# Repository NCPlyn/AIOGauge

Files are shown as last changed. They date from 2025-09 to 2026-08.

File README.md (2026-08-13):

# AIOGauge

All-In-One-Oil-Gauge; a ESP32S3 project that uses:
- **PST-F 1** Bosch pressure and temperature [sensor](https://www.bosch-motorsport.com/content/downloads/Raceparts/en-GB/54249355.html) (0261230482 / 0261230341 / 0261230340 etc + 1928405159 connector)
- **LSM6DS3** accelerometer for G force realtime monitor
- **ATGM336H** GPS for realtime speed monitor + 0-100km/h / 0-60mph 10Hz timer
- **GC9A01** round TFT display shows all information
- **Logs** last 10 hours of measurements to view later at 2Hz
- **WiFi** to update the firmware, change settings, view logged graphs of values and have **live view** alongs side the display!
- Two buttons to edit setting on the device itself
- **STLs** for 3D printed enclosure in /enclosure, screwed together with M3x16

**Project in development**

## Photos

<div style="display:flex">
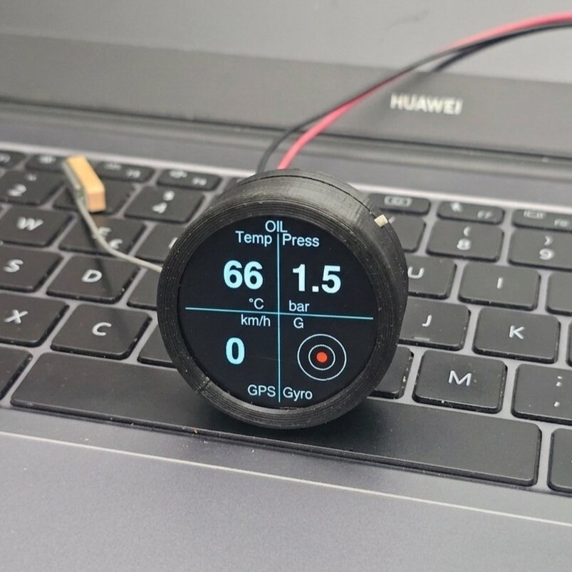
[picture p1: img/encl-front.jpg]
front

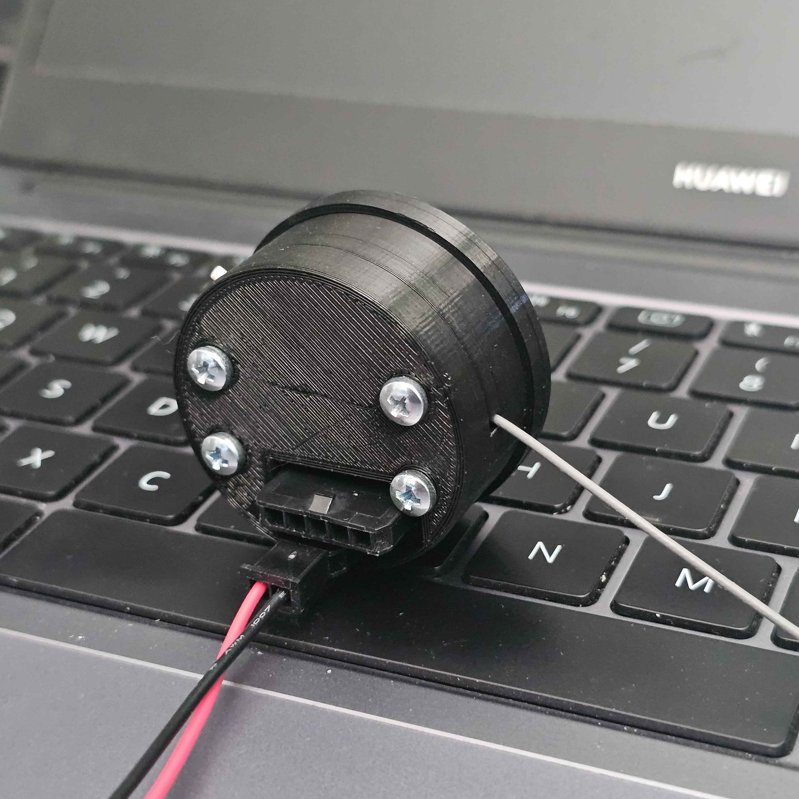
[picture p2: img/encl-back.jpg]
back

</div>
*Finished gauge in 3D printed enclosure*

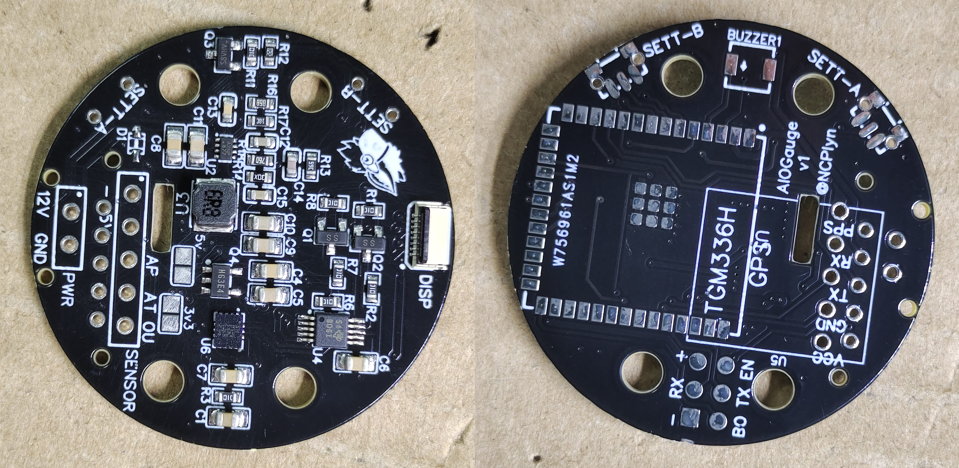
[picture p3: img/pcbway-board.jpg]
Prototype PCB
  
*PCBWay provided & preassembled PCB*  

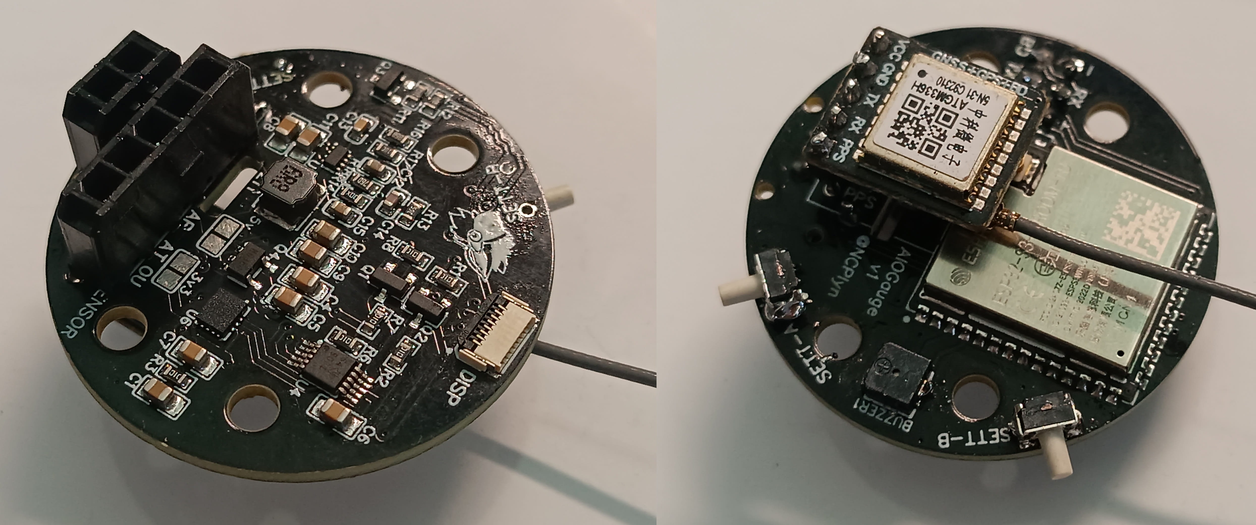
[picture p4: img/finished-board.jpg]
Assembled PCB
  
*Soldered rest of the components*  

## Sponsored by PCBWay

This project was made possible thanks to **[PCBWay](https://www.pcbway.com/)**, who kindly sponsored the **prototype PCBs** and handled the **SMD assembly**.

The PCBWay team discussed with me which parts would be sourced and used, and they were even able to assemble just a **single prototype board** - perfect for development. Before soldering, they sent me pictures of the component placement for confirmation, which gave me a lot of confidence in the build.  
  
The boards arrived quickly, the assembly quality was excellent, and I really appreciated the wide variety of PCB options available. 
If you’re looking for PCB prototyping or assembly, PCBWay offers quick turnaround, reliable manufacturing, and professional assembly services. 

PCBWay

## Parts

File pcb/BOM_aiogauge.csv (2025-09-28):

ID | Name | Designator | Footprint | Quantity | Manufacturer Part | Manufacturer | Supplier | Supplier Part | Price
1 | 4000Hz | BUZZER1 | BUZ-SMD_L4.0-W4.0-P3.50-L | 1 | FUET-4020 | FUET(福声科技) | LCSC | C391027 | 0.768
2 | ESP32-S3-WROOM-1U-N4 | U1 | WIRELM-SMD_ESP32-S3-WROOM-1U | 1 | ESP32-S3-WROOM-1U-N4 | ESPRESSIF(乐鑫) | LCSC | C2980296 | 3.601
3 | ATGM336H NEO-6M Module | U5 | ATGM336H NEO-6M | 1 | Teyleten Robot |  | LCSC
4 | TS36XL-6.0 180GF 072 | SW3,SW4 | SW-TH_SHOU-HAN_TS36XL-6.0 | 2 | TS36XL-6.0 180gf 072 | SHOU HAN(首韩) | LCSC | C2859427 | 0.126
5 | ESP flash pin | J1 | ESP32 FLASH PIN | 1
6 | PESD15VL1BA,115 | D1 | SOD-323_L1.8-W1.3-LS2.5-BI | 1 | PESD15VL1BA,115 | Nexperia(安世) | LCSC | C85378 | 0.043
7 | 6.8uH | U3 | IND-SMD_L4.0-W4.0 | 1 | ANR4030T6R8M | APV(爱普微) | LCSC | C6364812 | 0.037
8 | 2328702-8 | FPC1 | CONN-SMD_8P-P0.50-2328702-8 | 1 | 2328702-8 | TE Connectivity(泰科电子) | LCSC | C3168593 | 0.186
9 | C3004-WV02 | PWR | C3004-WV02 | 1 | C3004-WV02 | LHE | Electronics Source | 0376-0060-7
10 | solderbridge_top_1way_open_small | SB2,SB1 | SOLDERBRIDGE_TOP_1WAY_OPEN_SMALL | 2
11 | 1uF | C1 | C0805 | 1 | CL21B105KBFNNNE | SAMSUNG(三星) | LCSC | C28323 | 0.009
12 | 100nF | C4,C6,C7,C8 | C0805 | 4 | CL21B104KCFNNNE | SAMSUNG(三星) | LCSC | C28233 | 0.008
13 | 10uF | C5 | C0805 | 1 | CL21A106KAYNNNE | SAMSUNG(三星) | LCSC | C15850 | 0.011
14 | 22uF | C9,C10,C11 | C0805 | 3 | CL21A226MAQNNNE | SAMSUNG(三星) | LCSC | C45783 | 0.025
15 | 6.8nF | C12 | C0603 | 1 | 0603B682K500NT | FH(风华) | LCSC | C1631 | 0.003
16 | 1nF | C13 | C0603 | 1 | CL10B102KB8NNNC | SAMSUNG(三星) | LCSC | C1588 | 0.003
17 | 10pF | C14 | C0603 | 1 | CL10C100JB8NNNC | SAMSUNG(三星) | LCSC | C1634 | 0.005
18 | 1uF | C15 | C0603 | 1 | CL10A105KB8NNNC | SAMSUNG(三星) | LCSC | C15849 | 0.005
19 | BSS138 | Q1,Q2 | SOT-23-3_L2.9-W1.3-P1.90-LS2.4-BR | 2 | BSS138 | CJ(江苏长电/长晶) | LCSC | C78284 | 0.02
20 | IRLML6244 | Q3 | SOT-23-3_L2.9-W1.3-P1.90-LS2.4-BR | 1 | IRLML6244 | Hottech(合科泰) | LCSC | C5364311 | 0.039
21 | 10kΩ | R1,R2,R3,R6,R7,R8,R11 | R0603 | 7 | 0603WAF1002T5E | UNI-ROYAL(厚声) | LCSC | C25804 | 0.001
22 | 220Ω | R12 | R0603 | 1 | 0603WAF2200T5E | UNI-ROYAL(厚声) | LCSC | C22962 | 0.001
23 | 40.2kΩ | R13 | R0603 | 1 | AC0603FR-0740K2L | YAGEO(国巨) | LCSC | C327408 | 0.002
24 | 20Ω | R14 | R0603 | 1 | 0603WAF200JT5E | UNI-ROYAL(厚声) | LCSC | C22950 | 0.001
25 | 7.68kΩ | R16 | R0603 | 1 | AC0603FR-077K68L | YAGEO(国巨) | LCSC | C228059 | 0.002
26 | 15kΩ | R17 | R0603 | 1 | 0603WAF1502T5E | UNI-ROYAL(厚声) | LCSC | C22809 | 0.001
27 | 604kΩ | R18 | R0603 | 1 | AC0603FR-07604KL | YAGEO(国巨) | LCSC | C144646 | 0.002
28 | C3004-WV05 | SENSOR | C3004-WV05 | 1 | C3004-WV05 | LHE | Electronics Source | 0376-0060-7
29 | MP2393GTL-Z | U2 | SOT-583-8_L2.1-W1.2-P0.50-LS1.6-BL | 1 | MP2393GTL-Z | MPS(芯源) | LCSC | C6674609
30 | ADS1115IDGST | U4 | VSSOP-10_L3.0-W3.0-P0.50-LS4.9-BL | 1 | ADS1115IDGST | TI(德州仪器) | LCSC | C468683 | 1.717
31 | LSM6DS3TR | U6 | LGA-14_L3.0-W2.5-P0.50-TL | 1 | LSM6DS3TR | ST(意法半导体) | LCSC | C95230 | 1.299
32 | XC6220B331MR-G | Q4 | SOT-25_L3.0-W1.6-P0.95-LS2.8-TL | 1 | XC6220B331MR-G | TOREX(特瑞仕) | LCSC | C86534 | 0.442

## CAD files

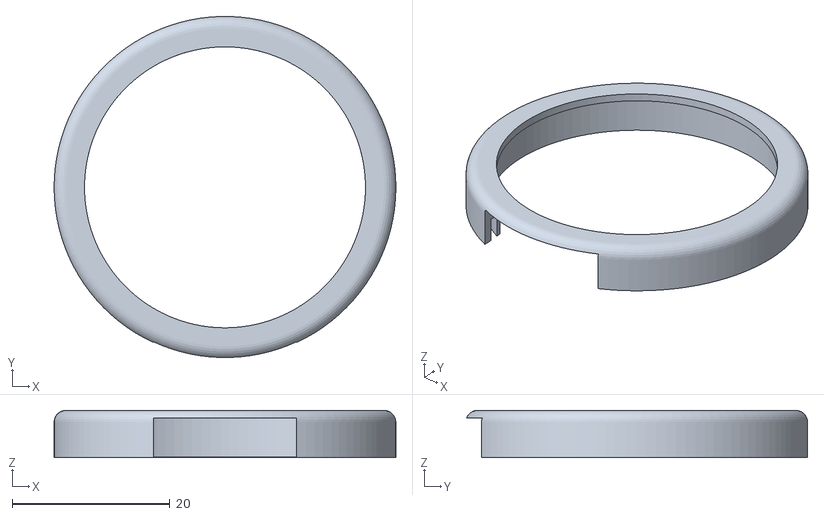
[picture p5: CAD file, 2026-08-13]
enclosure/aiofront.stl
43.3 x 43.2 x 6.00

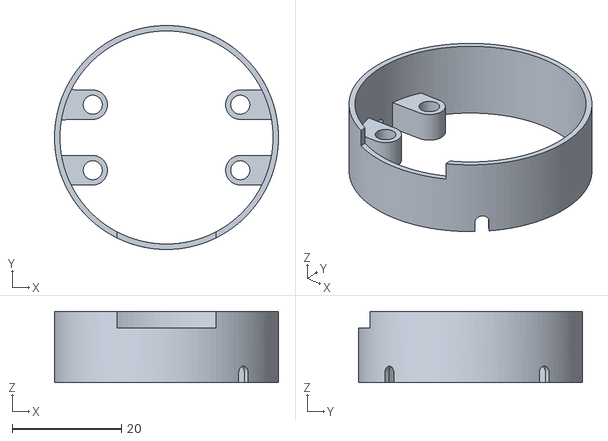
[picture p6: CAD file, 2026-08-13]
enclosure/aiobody.stl
41.0 x 41.0 x 13.0

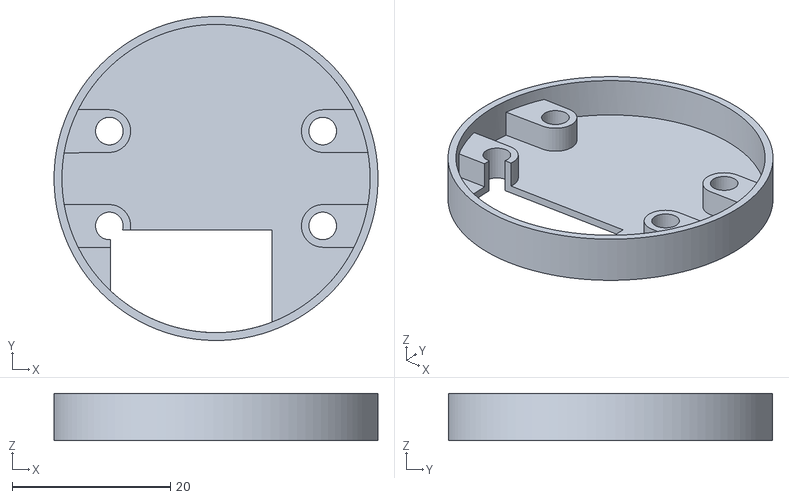
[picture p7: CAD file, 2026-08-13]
enclosure/aioback.stl
41.0 x 41.0 x 6.00

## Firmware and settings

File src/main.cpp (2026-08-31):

//AIOGauge >>> All-In-One-Oil-Gauge

/*
PCB fix:
- rotate screen connector 180°
- add resistor to temp (4.7k-5V)
- louder buzzer/tranzistor
- ESP32S3 without module + antenna (https://files.waveshare.com/wiki/ESP32-S3-Zero/ESP32-S3-Zero-Sch.pdf)
- relocate gps to back?
Write down sensor pinout to cable to PCB
*/

// ----- User Settings ----- (350, loads that if not saved)
int alarmTemp = 130; //above this temperature is alarm
float alarmPress = 1.0; //below this pressure is alarm
float pressSensMvPerBar = 400.0f; // PST-F 1 10 bar; web presets: 400 / 14.3 / 11.43
bool useImperial = false; //true for imperial, false for metric
bool usePSI = false; //true for PSI, false for bar
bool invertOutput = false; //true for pressureOutput = normally floating
bool buzzerEna = true; //enable or disable
bool dragEna = false; //enable or disable
bool tftEnabled = true; //physical TFT on/off (phone can be the screen)

//GPS Serial1 = ESP TX->17 (to GPS RXD), ESP RX<-18 (from GPS TXD)
//ADC I2C = SDA8, SCL9 via level shifter
//TFT SPI = MOSI11, CLK12, CS10, DC13, RST14
//BOSCH = TempA0+4.7k5v, PressA1
int pressureOutput = 15; //pressure alarm output pin, normally grounded
int buzzerOutput = 4;
int settA = 6, settB = 7;
int BL_PIN = 5;
int GPS_TX_PIN = 17; //ESP32 TX -> GPS RXD
int GPS_RX_PIN = 18; //ESP32 RX <- GPS TXD

//http://192.168.4.1/update for OTA, /log for logs
const char *otaSSID = "AIOGauge";
const char *otaPassword = "12345678";

// ----- Code -----
#include <TFT_eSPI.h>
#include <SPI.h>
#include "Free_Fonts.h"
#include <Wire.h>
#include <Adafruit_ADS1X15.h>
#include <SparkFunLSM6DS3.h>
#include <TinyGPS++.h>
#include <Preferences.h>
#include <WiFi.h>
#include <AsyncTCP.h>
#include <ESPAsyncWebServer.h>
#include <AsyncWebSocket.h>
#include <ElegantOTA.h>
#include <LittleFS.h>

Preferences preferences;
TinyGPSPlus gps;
Adafruit_ADS1115 ads;
TFT_eSPI tft = TFT_eSPI();
LSM6DS3 myIMU(I2C_MODE, 0x6A);
AsyncWebServer server(80);
AsyncWebSocket ws("/ws");

uint16_t colorTemp = 0x0000, colorPress = 0x0000, dragTime = 0, valupdate = 0, dragStart = 0, color;
bool gpsReady = false, lastOPval = false;
volatile bool tftPowerPending = false;
#define GPS_CMD_MAX 128
char gpsCmdBuf[GPS_CMD_MAX];
volatile bool gpsCmdPending = false;
long tempVal = 140, speedVal = 0, DnowSpeed = 0, DlastSpeed = 0, lastTemp = 0, bright = 100,lastSpeed = -10;
float pressVal = 0, fG = -5.0, sG = -5.0, lastPress = 0;
int lastDot[2] = {175, 175};

// ----- Ride logging -----
#define RIDE_BUDGET_BYTES (400 * 1024)
#define RIDE_BUF_SAMPLES 64
#define LOG_SAMPLE_MS 500

struct __attribute__((packed)) LogSample {
  int16_t press_x100; // bar * 100
  int16_t temp_c;     // °C
  int16_t speed_kmh;  // km/h; -1 if GPS invalid
};

LogSample rideBuf[RIDE_BUF_SAMPLES];
size_t rideBufCount = 0;
fs::File rideFile;
uint16_t currentRideId = 0;
unsigned long logupdate = 0;
bool rideLogging = false;

// ----- Drag result overlay -----
unsigned long dragShowUntil = 0;
unsigned long dragShowCurrent = 0;
unsigned long dragShowBest = 0;
bool dragShowNewBest = false;

void drawCenterText(int centerX, int centerY, int textSize, uint16_t fColor, uint16_t bColor, String text);
void drawUI();
void TFT_SET_BL(uint8_t Value);
void applyTftPower();
void showDragOverlay();
String liveToJson();
String formatDragMs(unsigned long ms);

// ----- Temperature Sensor Parameters -----
const float pullupResistor = 4600.0; //Pull-up resistor (ohms)
const float supplyVoltage = 5.0; //Supply voltage for the sensor circuit

// Temperature/Resistance Lookup table
const int tableSize = 16;
float temperatureTable[tableSize] = { -40, -30, -20, -10, 0, 10, 20, 30, 40, 50, 60, 70, 80, 90, 100, 110 };
float resistanceTable[tableSize]  = { 44864, 25524, 15067, 9195, 5784, 3740, 2480, 1683, 1167, 824, 594, 434.9, 323.4, 244, 186.6, 144.5 };

// ----- Pressure Sensor Parameters -----
// 0.5 V offset at 0 bar, ratiometric to 5 V. Scale is pressSensMvPerBar (web setting).
// PST-F 1 10 bar:  400 mV/bar   (0.5–4.5 V = 0–10 bar)
// PST-F 2 280 bar: 14.3 mV/bar  (0.5–4.5 V = 0–280 bar)
// PST-F 2 350 bar: 11.43 mV/bar (0.5–4.5 V = 0–350 bar)
const float PRESS_OFFSET_V = 0.5f;

// Function to linearly interpolate the temperature based on sensor resistance
float interpolateTemperature(float resistance) {
  if (resistance>resistanceTable[0]) { //Check for out-of-range values
    return temperatureTable[0];
  }
  if (resistance<resistanceTable[tableSize-1]) {
    return temperatureTable[tableSize-1];
  }
  for (int i = 0; i < tableSize - 1; i++) { //Find the segment in the table
    if (resistance <= resistanceTable[i] && resistance >= resistanceTable[i + 1]) {
      float t1 = temperatureTable[i];
      float t2 = temperatureTable[i + 1];
      float r1 = resistanceTable[i];
      float r2 = resistanceTable[i + 1];
      return t1 + (t2 - t1) * ((resistance - r1) / (r2 - r1)); //Linear interpolation formula
    }
  }
  return NAN; //Return NaN if interpolation fails
}

// ----- Misc funcs -----
//realtime logger
#define LOG_BUFFER_SIZE (50 * 1024)  // 50 KB
char *logBuffer = nullptr;
size_t logIndex = 0;
void logPrint(const char *str) {
  Serial.println(str);
  if (!logBuffer) return;
  size_t len = strlen(str);
  size_t needed = len + 1; //newline
  if (logIndex + needed >= LOG_BUFFER_SIZE) {
    logIndex = 0;
    logBuffer[0] = '\0';
  }
  memcpy(logBuffer + logIndex, str, len);
  logIndex += len;
  logBuffer[logIndex++] = '\n';
  logBuffer[logIndex] = '\0';
}
inline void logPrint(const __FlashStringHelper *str) {
  logPrint((const char*)str);
}
void logPrint(const String &str) {
    logPrint(str.c_str());
}

//Map function for float
float mapfloat(float x, float in_min, float in_max, float out_min, float out_max) {
  return (x - in_min) * (out_max - out_min) / (in_max - in_min) + out_min;
}

//Screen dimming (0 = off, 1–100 = brightness %)
void TFT_SET_BL(uint8_t Value) {
  if (Value > 100) {
    printf("TFT_SET_BL Error \r\n");
  } else {
    ledcWrite(BL_PIN, (uint32_t)(Value * 2.55f));
  }
}

void invalidateGaugeCaches() {
  lastTemp = -2;
  lastPress = -2;
  lastSpeed = -2;
  colorTemp = TFT_RED;
  colorPress = TFT_RED;
  lastDot[0] = 175;
  lastDot[1] = 175;
}

void applyTftPower() {
  if (tftEnabled) {
    TFT_SET_BL((uint8_t)bright);
    if (dragShowUntil != 0) {
      showDragOverlay();
    } else {
      tft.fillScreen(TFT_BLACK);
      drawUI();
      invalidateGaugeCaches();
    }
  } else {
    TFT_SET_BL(0);
  }
}

// ----- GPS auto-baud detect & configure -----
//Waits up to timeoutMs on the CURRENT Serial1 baud rate for a checksum-validNMEA sentence.
bool gpsBaudIsValid(uint32_t timeoutMs) {
  TinyGPSPlus probe;
  unsigned long start = millis();
  while (millis() - start < timeoutMs) {
    while (Serial1.available() > 0) {
      if (probe.encode(Serial1.read())) {
        return true; //got a full, checksum-valid sentence at this baud
      }
    }
  }
  return false;
}

//Sends the CASIC config strings to reconfigure the ATGM336H module.
void sendGPSConfig() {
  Serial1.println("$PCAS04,1*18"); //GPS only (no BDS/GLONASS)
  delay(100);
  Serial1.println("$PCAS11,3*1E"); //automotive mode
  delay(100);
  Serial1.println("$PCAS03,1,0,0,0,1,0,0,,,,,,,*32"); //only GGA+RMC output
  delay(100);
  Serial1.println("$PCAS02,100*1E"); //10Hz update rate
  delay(100);
  Serial1.println("$PCAS01,5*19"); //baud -> 115200 (module switches now)
  delay(200);
}

//Append NMEA XOR checksum (*HH) if the sentence has $ and no checksum yet.
String applyNmeaChecksum(String s) {
  s.trim();
  if (s.length() == 0) return s;
  if (s.charAt(0) == '$' && s.indexOf('*') < 0) {
    uint8_t cs = 0;
    for (unsigned i = 1; i < s.length(); i++) {
      cs ^= (uint8_t)s.charAt(i);
    }
    char hex[5];
    snprintf(hex, sizeof(hex), "*%02X", cs);
    s += hex;
  }
  return s;
}

void flushGpsCmd() {
  if (!gpsCmdPending) return;
  Serial1.println(gpsCmdBuf);
  logPrint(String("GPS cmd sent: ") + gpsCmdBuf);
  gpsCmdPending = false;
}

//Detects current module state and gets it (and our UART) onto 115200/10Hz/GPS-only.
void setupGPS() {
  //Assume normal operating state first: 115200
  Serial1.begin(115200, SERIAL_8N1, GPS_RX_PIN, GPS_TX_PIN);
  delay(50);
  Serial1.flush();
  while (Serial1.available()) { Serial1.read(); } //clear any boot garbage
  if (gpsBaudIsValid(1500)) {
    logPrint("GPS: already running at 115200, skipping reconfigure");
    return;
  }

  //Fell back to factory default 9600 (e.g. battery-backed RAM lost after low VBAT)
  Serial1.begin(9600, SERIAL_8N1, GPS_RX_PIN, GPS_TX_PIN);
  delay(50);
  Serial1.flush();
  while (Serial1.available()) { Serial1.read(); }
  if (gpsBaudIsValid(1500)) {
    logPrint("GPS: found at 9600 (default), sending reconfigure...");
    sendGPSConfig();
    Serial1.begin(115200, SERIAL_8N1, GPS_RX_PIN, GPS_TX_PIN);
    delay(100);
    Serial1.println("$PCAS00*01");  // save to flash
    delay(200);
    logPrint("GPS: reconfigured and switched to 115200");
    return;
  }

  //Neither responded (module still booting / not connected) - default to 115200
  logPrint("GPS: no response at 115200 or 9600, defaulting to 115200");
  Serial1.begin(115200, SERIAL_8N1, GPS_RX_PIN, GPS_TX_PIN);
}

//RGB stuff
uint16_t hsvToRgb(uint8_t hue) {
    float r, g, b;
    float h = hue / 255.0 * 360.0;
    int i = h / 60;
    float f = (h / 60) - i;
    float q = 1 - f, t = f;
    switch (i % 6) {
      case 0: r = 1; g = t; b = 0; break;
      case 1: r = q; g = 1; b = 0; break;
      case 2: r = 0; g = 1; b = t; break;
      case 3: r = 0; g = q; b = 1; break;
      case 4: r = t; g = 0; b = 1; break;
      default: r = 1; g = 0; b = q; break;
    }
    return tft.color565(r * 255, g * 255, b * 255);
}
uint8_t hue = 0;

String formatDragMs(unsigned long ms) {
  if (ms == 0) {
    return "None";
  }
  unsigned long seconds = ms / 1000;
  int decimal = (ms % 1000) / 10;
  char buf[16];
  snprintf(buf, sizeof(buf), "%lu.%02ds", seconds, decimal);
  return String(buf);
}

String getStringTime() {
  return formatDragMs(dragTime);
}

// ----- Ride logger -----
String ridePath(uint16_t id) {
  char buf[20];
  snprintf(buf, sizeof(buf), "/r/%04u.bin", id);
  return String(buf);
}

size_t totalRideBytes() {
  size_t total = 0;
  fs::File root = LittleFS.open("/r");
  if (!root || !root.isDirectory()) {
    return 0;
  }
  fs::File f = root.openNextFile();
  while (f) {
    if (!f.isDirectory()) {
      total += f.size();
    }
    f = root.openNextFile();
  }
  return total;
}

bool deleteOldestRide() {
  int oldest = -1;
  fs::File root = LittleFS.open("/r");
  if (!root || !root.isDirectory()) {
    return false;
  }
  fs::File f = root.openNextFile();
  while (f) {
    if (!f.isDirectory()) {
      String name = f.name();
      int slash = name.lastIndexOf('/');
      if (slash >= 0) {
        name = name.substring(slash + 1);
      }
      int id = name.toInt();
      if (id > 0 && id != (int)currentRideId && (oldest < 0 || id < oldest)) {
        oldest = id;
      }
    }
    f = root.openNextFile();
  }
  if (oldest < 0) {
    return false;
  }
  String path = ridePath((uint16_t)oldest);
  if (LittleFS.remove(path)) {
    logPrint("Ride logger: deleted oldest " + path);
    return true;
  }
  return false;
}

void enforceRideBudget(size_t extraBytes) {
  while (totalRideBytes() + extraBytes > RIDE_BUDGET_BYTES) {
    if (!deleteOldestRide()) {
      break;
    }
  }
}

void flushLog() {
  if (!rideLogging || rideBufCount == 0 || !rideFile) {
    return;
  }
  size_t bytes = rideBufCount * sizeof(LogSample);
  enforceRideBudget(bytes);
  if (totalRideBytes() + bytes > RIDE_BUDGET_BYTES) {
    logPrint("Ride logger: budget full, dropping samples");
    rideBufCount = 0;
    return;
  }
  size_t written = rideFile.write((uint8_t *)rideBuf, bytes);
  rideFile.flush();
  if (written != bytes) {
    logPrint("Ride logger: short write");
  }
  rideBufCount = 0;
}

void logSample() {
  if (!rideLogging) {
    return;
  }
  LogSample s;
  float pressBar = usePSI ? (pressVal / 14.5038f) : pressVal;
  long tempC = useImperial ? (long)round((tempVal - 32) * 5.0 / 9.0) : tempVal;
  long speedKmh = (speedVal < 0) ? -1 : (useImperial ? (long)round(speedVal * 1.60934) : speedVal);
  s.press_x100 = (int16_t)round(pressBar * 100.0f);
  s.temp_c = (int16_t)tempC;
  s.speed_kmh = (int16_t)speedKmh;
  rideBuf[rideBufCount++] = s;
  if (rideBufCount >= RIDE_BUF_SAMPLES) {
    flushLog();
  }
}
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
void loop(void) {
  ElegantOTA.loop(); //services pending OTA update/reboot requests

  if (tftPowerPending) {
    tftPowerPending = false;
    applyTftPower();
  }

  flushGpsCmd();

  //Feed gps
  while(Serial1.available() > 0) {
    if(gps.encode(Serial1.read())) {
      if(!gps.location.isValid() || gps.location.age() > 2000 || gps.satellites.value() < 2) {
        gpsReady = false;
      } else {
        gpsReady = true;
      }
    }
  }

  // Clear drag overlay after 5s and resume gauges
  if (dragShowUntil != 0 && (long)(millis() - dragShowUntil) >= 0) {
    clearDragOverlayAndResume();
  }

  if(gpsReady && dragEna && dragShowUntil == 0) {
    DnowSpeed = gps.speed.kmph();
    if(DlastSpeed < 2 && DnowSpeed >= 2 && dragStart == 0) {
      dragStart = millis();
    }
    if(dragStart != 0 && ((useImperial)?(DnowSpeed>=60):(DnowSpeed>=100))) {
      unsigned long currentDrag = millis()-dragStart;
      bool isNewBest = (dragTime == 0 || currentDrag < dragTime);
      if(isNewBest) {
        dragTime = (uint16_t)currentDrag;
        preferences.begin("settings", false);
        preferences.putULong("dragTime",dragTime);
        preferences.end();
      }
      dragShowCurrent = currentDrag;
      dragShowBest = dragTime;
      dragShowNewBest = isNewBest;
      dragShowUntil = millis() + 5000;
      showDragOverlay();
      dragStart = 0;
    }
    if (dragStart != 0 && (millis()-dragStart) > 30000) {
      dragStart = 0;
    }
    DlastSpeed = DnowSpeed;
  }

  //Update values every 100ms (skip gauge draws while drag result is on screen or TFT off)
  if((millis()-valupdate)>100) {
    tempVal = getTemp(useImperial);
    pressVal = round(getPress(usePSI) * 10) / 10.0;
    speedVal = getSpeed(useImperial);
    fG = myIMU.readFloatAccelZ();
    sG = myIMU.readFloatAccelX();
    if (tftEnabled && dragShowUntil == 0) {
      drawG(fG,sG);
      drawTemp(tempVal,useImperial);
      drawPress(pressVal,usePSI);
      drawSpeed(speedVal);
      hue = (hue + 1) % 256;
      color = hsvToRgb(hue);
      tft.drawFastHLine(0, 120, 240, color);
      tft.drawFastVLine(120, 18, 222, color);
    } else if (!tftEnabled) {
      updateAlarmOutputs();
    }
    if (ws.count() > 0) {
      ws.textAll(liveToJson());
    }
    ws.cleanupClients();
    valupdate = millis();
  }

  //Log SI samples every 0.5s; flush buffer about every 8s
  if ((millis() - logupdate) >= LOG_SAMPLE_MS) {
    logSample();
    static uint8_t flushTicks = 0;
    if (++flushTicks >= 16) { // 16 * 0.5s = 8s
      flushLog();
      flushTicks = 0;
    }
    logupdate = millis();
  }

  //Settings menu
  if(digitalRead(settA) == LOW) { 
    bool loopVar = true, drawRun = true;
    unsigned long debounce = 0;
    int currentMenu = 0, textSide = 75, valueSide = 185, paddValue = 50, paddText = 142, downAmnt = 65;
    if (!tftEnabled) {
      TFT_SET_BL((uint8_t)bright); //temporarily light so menu is visible
    }
    tft.fillScreen(TFT_BLACK);
    tft.setTextColor(TFT_WHITE, TFT_BLACK);
    tft.setFreeFont(FSS9);
    tft.setTextDatum(MC_DATUM);
    tft.drawString("Settings",120,20);
    if(useImperial) {
      tft.drawString("0-60mph: "+getStringTime(),120,40);
    } else {
      tft.drawString("0-100kph: "+getStringTime(),120,40);
    }
    while(digitalRead(settA) == LOW){delay(10);};
    while(loopVar) {
      if(currentMenu == 0) { //Temp alarm trigger point
        if(digitalRead(settB) == LOW) {
          debounce = millis();
          while(digitalRead(settB) == LOW) {
            if(millis()>debounce+1000) {
              alarmTemp++;
              if(useImperial) {
                if(alarmTemp > 300) {
                  alarmTemp = 80;
                }
              } else {
                if(alarmTemp > 150) {
                  alarmTemp = 80;
                }
              }
              tft.drawNumber(alarmTemp, valueSide, downAmnt+(17*currentMenu));
              delay(20);
            }
          }
          alarmTemp++;
          if(useImperial) {
            if(alarmTemp > 300) {
              alarmTemp = 80;
            }
          } else {
            if(alarmTemp > 150) {
              alarmTemp = 80;
            }
          }
          tft.drawNumber(alarmTemp, valueSide, downAmnt+(17*currentMenu));
          delay(10);
        }
        if(digitalRead(settA) == LOW || drawRun) {
          tft.setTextPadding(paddText);
          tft.drawString("Temp Alarm:", textSide, downAmnt+(17*(currentMenu)));
          currentMenu++;
          tft.drawString("> Press Alarm: <", textSide, downAmnt+(17*(currentMenu)));
          tft.setTextPadding(paddValue);
          tft.drawFloat(alarmPress, 1, valueSide, downAmnt+(17*(currentMenu)));
          while(digitalRead(settA) == LOW && !drawRun){delay(10);};
        }
      }
      if(currentMenu == 1) { //Press alarm trigger point
        if(digitalRead(settB) == LOW) {
          debounce = millis();
          while(digitalRead(settB) == LOW) {
            if(millis()>debounce+1000) {
              if(usePSI) {
                alarmPress+=1;
                if(alarmPress > 30) {
                  alarmPress = 0;
                }
              } else {
                alarmPress+=0.1;
                if(alarmPress > 3.0) {
                  alarmPress = 0.0;
                }
              }
              tft.drawFloat(alarmPress, 1, valueSide, downAmnt+(17*currentMenu));
              delay(20);
            }
          }
          if(usePSI) {
            alarmPress+=10;
            if(alarmPress > 300) {
              alarmPress = 0;
            }
          } else {
            alarmPress+=0.1;
            if(alarmPress > 3.0) {
              alarmPress = 0.0;
            }
          }
          tft.drawFloat(alarmPress, 1, valueSide, downAmnt+(17*currentMenu));
          delay(10);
        }
        if(digitalRead(settA) == LOW || drawRun) {
          tft.setTextPadding(paddText);
          tft.drawString("Press Alarm:", textSide, downAmnt+(17*(currentMenu)));
          currentMenu++;
          tft.drawString("> Use PSI: <", textSide, downAmnt+(17*(currentMenu)));
          tft.setTextPadding(paddValue);
          tft.drawString(((usePSI)?"True":"False"), valueSide, downAmnt+(17*(currentMenu)));
          while(digitalRead(settA) == LOW && !drawRun){delay(10);};
        }
      }
      if(currentMenu == 2) { //bar/PSI
        if(digitalRead(settB) == LOW) {
          usePSI = !usePSI;
          tft.drawString(((usePSI)?"True":"False"), valueSide, downAmnt+(17*currentMenu));
          while(digitalRead(settB) == LOW){delay(10);};
        }
        if(digitalRead(settA) == LOW || drawRun) {
          tft.setTextPadding(paddText);
          tft.drawString("Use PSI:", textSide, downAmnt+(17*(currentMenu)));
          currentMenu++;
          tft.drawString("> Use imperial: <", textSide, downAmnt+(17*(currentMenu)));
          tft.setTextPadding(paddValue);
          tft.drawString(((useImperial)?"True":"False"), valueSide, downAmnt+(17*(currentMenu)));
          while(digitalRead(settA) == LOW && !drawRun){delay(10);};
        }
      }
      if(currentMenu == 3) { //imperial/metric
        if(digitalRead(settB) == LOW) {
          useImperial = !useImperial;
          tft.drawString(((useImperial)?"True":"False"), valueSide, downAmnt+(17*currentMenu));
          while(digitalRead(settB) == LOW){delay(10);};
        }
        if(digitalRead(settA) == LOW || drawRun) {
          tft.setTextPadding(paddText);
          tft.drawString("Use imperial:", textSide, downAmnt+(17*(currentMenu)));
          currentMenu++;
          tft.drawString("> Invert output: <", textSide, downAmnt+(17*(currentMenu)));
          tft.setTextPadding(paddValue);
          tft.drawString(((invertOutput)?"True":"False"), valueSide, downAmnt+(17*(currentMenu)));
          while(digitalRead(settA) == LOW && !drawRun){delay(10);};
        }
      }
      if(currentMenu == 4) { //invert output
        if(digitalRead(settB) == LOW) {
          invertOutput = !invertOutput;
          tft.drawString(((invertOutput)?"True":"False"), valueSide, downAmnt+(17*currentMenu));
          while(digitalRead(settB) == LOW){delay(10);};
        }
        if(digitalRead(settA) == LOW || drawRun) {
          tft.setTextPadding(paddText);
          tft.drawString("Invert output:", textSide, downAmnt+(17*(currentMenu)));
          currentMenu++;
          tft.drawString("> Alarm buzzer: <", textSide, downAmnt+(17*(currentMenu)));
          tft.setTextPadding(paddValue);
          tft.drawString(((buzzerEna)?"True":"False"), valueSide, downAmnt+(17*(currentMenu)));
          while(digitalRead(settA) == LOW && !drawRun){delay(10);};
        }
      }
      if(currentMenu == 5) { //buzzer
        if(digitalRead(settB) == LOW) {
          buzzerEna = !buzzerEna;
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

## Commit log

2025-09-28 git init
    [4MB_17-17-05.csv, BOM_aiogauge.csv, PickAndPlace_PCB_aiogauge.csv]
2026-07-31 Accy,GPS,sensor fixes and added WiFi with OTA/log
    [main.cpp]
2026-08-13 live view, logging, graphs etc.
    [aioback.stl, aiobody.stl, aiofront.stl]
